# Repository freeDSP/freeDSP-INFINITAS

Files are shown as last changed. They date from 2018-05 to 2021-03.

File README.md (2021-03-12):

# freeDSP Infinitas

USB Audio Class 2 compliant audio interface with up to 32 input and up to 32 output channels and optional ADAU1452 DSP.

BOARD STATUS: RELEASED!

MAIN COORDINATOR: [dspverden](https://github.com/dspverden)

DOCUMENTATION: [Getting Started](https://docs.google.com/document/d/1jxKOcB1Af_6xawysrgFLgatrspSJ-aYZdDhTxlWoG2I)

IMPORTANT:

Please take care on which branch you're currently working!

Branches:

master - this branch always holds the latest released revision

develop - this is the develop branch with new features

## License
This work is licensed under <br />Dieses Werk ist lizenziert unter einer <a rel="license" href="http://creativecommons.org/licenses/by-nc-sa/4.0/">Creative Commons Namensnennung - Nicht-kommerziell - Weitergabe unter gleichen Bedingungen 4.0 International Lizenz</a>.

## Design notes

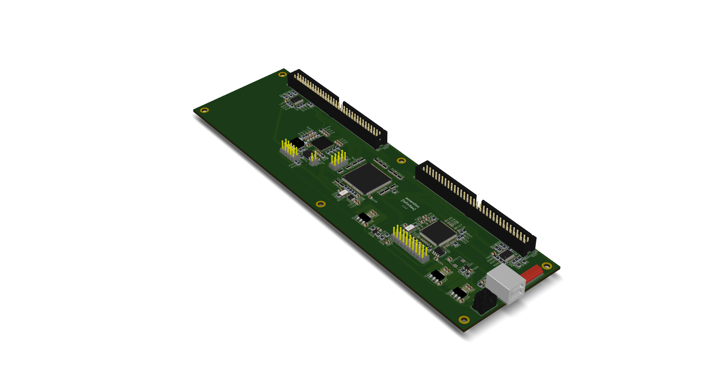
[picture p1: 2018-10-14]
SOURCES/KICAD/infinitas.png

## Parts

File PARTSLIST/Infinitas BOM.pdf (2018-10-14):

### [Infinitas] Core rev 1.0.0 BOM

Reference | Qty | Value1 | Value2 | Footprint | Order No. digikey
B101 B102 B103 B104 B105 B106 | 6 | - | - | MountingHole_3.2mm_M3_DIN965_Pad | -
C102 C122 C125 C127 C128 C130 C131 C133 C205 C206 | 10 | 10u0 | 20% 25V X5R | C0805-X7R | 490-10748-1-ND
C101 C103 C104 C105 C106 C107 C108 C109 C110 C111 C112 C113 C114 C115 C116 C117 C118 C119 C120 C121 C124 C126 C129 C132 C202 C203 C204 C207 | 28 | 100n | 5% 50V X7R | C0805-X7R | 399-1170-1-ND
C123 | 1 | 22u0 | 20% 10V X5R | C0805-X7R | 490-10511-1-ND
C201 | 1 | 10n0 | 10% 50V X7R | C0805-X7R | 311-1136-1-ND
C208 | 1 | 1n00 | 10% 50V X7R | C0805-X7R | 399-1147-1-ND
C209 C210 C211 C212 C213 C214 C215 C216 C217 C218 C219 C220 C221 C222 C223 C224 C225 C226 C227 C228 C229 C230 C231 C232 C233 | 25 | 100n | 10% 10V X7R | C_0402 | 490-6321-1-ND
D201 | 1 | MBR120VLSFT | Schottky 20V 1 A | SOD123 | MBR120VLSFT3GOSCT-ND
IC101 | 1 | CS2100CP | Fractional-N Clock Multiplier | MSOP-10_3x3mm_Pitch0.5mm | 598-1750-ND
IC102 IC103 | 2 | PCA9545APW | I2C Switch 4ch | TSSOP-20_4.4x6.5mm_Pitch0.65mm | 568-1865-1-ND
IC104 | 1 | LCMXO2-1200HC-6TG144C | FPGA | TQFP-144_20x20mm_Pitch0.5mm | 220-2040-ND
IC105 | 1 | TLV62565 | 1.5A | SOT-23-5 | 296-43657-1-ND
IC106 | 1 | ADM811TARTZ | Spannungsmonitor | SOT-143 | ADM811TARTZ-REELCT-ND
IC107 | 1 | LM1117MP-5.0 | LDO | SOT223 | LM1117MP-5.0/NOPBCT-ND
IC108 IC109 | 2 | NCP1117LPST33 | LDO | SOT223 | NCP1117LPST33T3GOSCT-ND
IC201 | 1 | XE216-512-TQ128 | xCore | TQFP-128_14x14mm_Pitch0.4mm_EP_Handsoldering | 880-1096-ND
IC202 | 1 | NCP4681DSQ25T1G | 2,5V 150mA | SC-70-5 | NCP4681DSQ25T1GOSCT-ND
IC203 | 1 | IS25LP080D | 8Mb | SOIC8_3.9x4.9mm_Pitch1.27mm | 706-1580-ND
IC204 | 1 | NC7WZ07 | Noninverting Buffer | SC-70-6 | NC7WZ07P6XCT-ND
L101 | 1 | 2u20 | 30% 4.5A 26 mOhm | MCSDRH73B | 811-1157-1-ND
OSC101 | 1 | 24M576 | - | ASFL1 | 300-8253-1-ND
OSC201 | 1 | 24M0 | - | ASFL1 | 300-8252-1-ND
R101 R201 R213 R214 | 4 | 10K0 | 1% 0.125W Thick | C0805-RES | 311-10.0KCRCT-ND
R118 | 1 | 4K70 | 1% 0.125W Thick | C0805-RES | 311-4.70KCRCT-ND
R102 R103 R104 R105 R112 R113 R114 R115 R124 R125 R126 R127 R134 R135 R136 R137 R211 R212 | 18 | 2K00 | 1% 0.125W Thick | C0805-RES | 311-2.00KCRCT-ND
R106 R107 R108 R109 R110 R111 R128 R129 R130 R131 R132 R133 | 12 | 47K0 | 1% 0.125W Thick | C0805-RES | 311-47.0KCRCT-ND

1

freeDSP Option
C301 C304 C308 C313 | 4 | 10u0 | 20% 25V X5R | C0805-X7R | 490-10748-1-ND
C302 C305 C307 C309 C310 C311 C312 C314 C315 C316 C317 | 11 | 100n | 5% 50V X7R | C0805-X7R | 399-1170-1-ND
C303 | 1 | 5n60 | 10% 50V X7R | C0805-X7R | 311-1134-1-ND
C306 | 1 | 150p | 5% 50V C0G | C0805-X7R | 399-1125-1-ND
FER301 FER302 | 2 | 600R | @100MHz 600mA | C0805-RES | 490-1040-1-ND
IC301 | 1 | ADAU1452 | - | QFP72_10x10_EP_Handsoldering | ADAU1452WBCPZ-ND
IC302 | 1 | 25AA1024 | 1Mbit | SOIJ-8_5.3x5.3mm_Pitch1.27mm | 25AA1024T-I/SMCT-ND
JP301 | 1 | Jumper | - | HDR_01x02 | 732-5315-ND
Q301 | 1 | STD2805 | PNP 60V 5A 150MHz 15W | TO-252-2Lead | 497-7465-1-ND
R308 R313 R314 | 3 | 10K0 | 1% 0.125W Thick | C0805-RES | 311-10.0KCRCT-ND
R302 R303 R304 R305 R306 | 5 | 51R0 | 1% 0.125W Thick | C0805-RES | 311-51.0CRCT-ND
R301 | 1 | 1K00 | 1% 0.125W Thick | C0805-RES | 311-1.00KCRCT-ND
R307 | 1 | 4K32 | 1% 0.125W Thick | C0805-RES | 311-4.32KCRCT-ND
R309 R310 R315 R316 | 4 | DNP | - | C0805-RES | -
R311 R312 R317 R318 | 4 | 0R00 | 1% 0.125W Thick | C0805-RES | 311-0.0ARCT-ND
X301 | 1 | HDR-02x05 | - | HDR_02x05 | 952-2117-ND
Reference | Qty | Value1 | Value2 | Footprint | Order No. digikey
R119 R120 R121 R123 R138 R139 R140 R141 R143 R145 R147 R148 R150 R151 R152 R204 | 16 | 51R0 | 5% 62,5mW | R_Array_Convex_4x0603 | TC164J-51CT-ND
R116 R117 R122 R142 R144 R146 R149 R202 R205 R206 R209 R210 | 12 | 51R0 | 1% 0.125W Thick | C0805-RES | 311-51.0CRCT-ND
R153 R207 | 2 | 1K00 | 1% 0.125W Thick | C0805-RES | 311-1.00KCRCT-ND
R154 | 1 | 80K6 | 1% 0.125W Thick | C0805-RES | 311-80.6KCRCT-ND
R155 R215 | 2 | 100K | 1% 0.125W Thick | C0805-RES | 311-100KCRCT-ND
R156 | 1 | 120K | 1% 0.125W Thick | C0805-RES | 311-120KCRCT-ND
R203 | 1 | 4R70 | 1% 0.125W Thick | C0805-RES | 311-4.70CRCT-ND
R208 | 1 | 43R2 | 1% 0.125W Thick | C0805-RES | P43.2CCT-ND
X101 | 1 | HDR-02x04 | - | HDR_02x04 | 952-3276-ND
X102 X103 | 2 | IDC64 | - | IDC64 | ED10532-ND
X104 | 1 | MicroMatch-10 | - | MM-10G | A110869-ND
X105 | 1 | MicroFit3 02x02 | - | Microfit3_43045-0428 | WM10670-ND
X201 | 1 | HDR-02x10 | - | HDR_02x10 | S2011EC-10-ND
X202 | 1 | USB_B | horizontal | USB_B | ED2983-ND
X203 | 1 | HDR-01x04 | - | HDR_01x04 | 732-5317-ND

2

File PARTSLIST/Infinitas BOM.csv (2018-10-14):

Reference | Quantity | Value | Footprint | Datasheet | Value1 | Value2 | digikey
B101 B102 B103 B104 B105 B106 | 6 | TEST_1P | rklib:MountingHole_3.2mm_M3_DIN965_Pad |  | - | - | -
C102 C122 C125 C127 C128 C130 C131 C133 C205 C206 C301 C304 C308 C313 | 14 | CAP_10u0_25V_X5R_0805 | rklib:C0805-X7R |  | 10u0 | 20% 25V X5R | 490-10748-1-ND
C101 C103 C104 C105 C106 C107 C108 C109 C110 C111 C112 C113 C114 C115 C116 C117 C118 C119 C120 C121 C124 C126 C129 C132 C202 C203 C204 C207 C302 C305 C307 C309 C310 C311 C312 C314 C315 C316 C317 | 39 | CAP_100n_50V_X7R_0805 | rklib:C0805-X7R |  | 100n | 5% 50V X7R | 399-1170-1-ND
C123 | 1 | CAP_22u0_10V_X5R_0805 | rklib:C0805-X7R |  | 22u0 | 20% 10V X5R | 490-10511-1-ND
C201 | 1 | CAP_10n0_50V_X7R_0805 | rklib:C0805-X7R |  | 10n0 | 10% 50V X7R | 311-1136-1-ND
C208 | 1 | CAP_1n00_50V_X7R_0805 | rklib:C0805-X7R |  | 1n00 | 10% 50V X7R | 399-1147-1-ND
C209 C210 C211 C212 C213 C214 C215 C216 C217 C218 C219 C220 C221 C222 C223 C224 C225 C226 C227 C228 C229 C230 C231 C232 C233 | 25 | CAP_100n_10V_X7R_0402 | Capacitors_SMD:C_0402 |  | 100n | 10% 10V X7R | 490-6321-1-ND
C303 | 1 | CAP_5n60_50V_X7R_0805 | rklib:C0805-X7R |  | 5n60 | 10% 50V X7R | 311-1134-1-ND
C306 | 1 | CAP_150p_50V_C0G_0805 | rklib:C0805-X7R |  | 150p | 5% 50V C0G | 399-1125-1-ND
D201 | 1 | DIO_MBR120VLSFT | rklib:SOD123 |  | MBR120VLSFT | Schottky 20V 1 A | MBR120VLSFT3GOSCT-ND
FER301 FER302 | 2 | FER_600R_600MA_0805 | rklib:C0805-RES |  | 600R | @100MHz 600mA | 490-1040-1-ND
IC101 | 1 | IC_CS2100CP | Housings_SSOP:MSOP-10_3x3mm_Pitch0.5mm |  | CS2100CP | Fractional-N Clock Multiplier | 598-1750-ND
IC102 IC103 | 2 | IC_PCA9545APW | Housings_SSOP:TSSOP-20_4.4x6.5mm_Pitch0.65mm |  | PCA9545APW | I2C Switch 4ch | 568-1865-1-ND
IC104 | 1 | IC_LCMXO2-1200HC-6TG144C | Housings_QFP:TQFP-144_20x20mm_Pitch0.5mm |  | LCMXO2-1200HC-6TG144C | FPGA | 220-2040-ND
IC105 | 1 | IC_TLV62565 | TO_SOT_Packages_SMD:SOT-23-5 |  | TLV62565 | 1.5A | 296-43657-1-ND
IC106 | 1 | IC_ADM811TARTZ | TO_SOT_Packages_SMD:SOT-143 |  | ADM811TARTZ | Spannungsmonitor | ADM811TARTZ-REELCT-ND
IC107 | 1 | IC_LM1117MP-5.0 | rklib:SOT223 |  | LM1117MP-5.0 | LDO | LM1117MP-5.0/NOPBCT-ND
IC108 IC109 | 2 | IC_NCP1117LPST33 | rklib:SOT223 |  | NCP1117LPST33 | LDO | NCP1117LPST33T3GOSCT-ND
IC201 | 1 | IC_XE216-512-TQ128 | rklib:TQFP-128_14x14mm_Pitch0.4mm_EP_Handsoldering |  | XE216-512-TQ128 | xCore | 880-1096-ND
IC202 | 1 | IC_NCP4681DSQ25T1G | TO_SOT_Packages_SMD:SC-70-5 |  | NCP4681DSQ25T1G | 2,5V 150mA | NCP4681DSQ25T1GOSCT-ND
IC203 | 1 | IC_IS25LP080D | rklib:SOIC8_3.9x4.9mm_Pitch1.27mm |  | IS25LP080D | 8Mb | 706-1580-ND
IC204 | 1 | IC_NC7WZ07 | TO_SOT_Packages_SMD:SC-70-6 |  | NC7WZ07 | Noninverting Buffer | NC7WZ07P6XCT-ND
IC301 | 1 | IC_ADAU1452 | rklib:QFP72_10x10_EP_Handsoldering |  | ADAU1452 | - | ADAU1452WBCPZ-ND
IC302 | 1 | IC_25AA1024 | Housings_SOIC:SOIJ-8_5.3x5.3mm_Pitch1.27mm |  | 25AA1024 | 1Mbit | 25AA1024T-I/SMCT-ND
JP301 | 1 | CON_JUMPER | rklib:HDR_01x02 |  | Jumper | - | 732-5315-ND
L101 | 1 | IND_2U20_30%_4A5 | rklib:MCSDRH73B |  | 2u20 | 30% 4.5A 26 mOhm | 811-1157-1-ND
OSC101 | 1 | OSC_24M576 | rklib:ASFL1 |  | 24M576 | - | 300-8253-1-ND
OSC201 | 1 | OSC_24M0 | rklib:ASFL1 |  | 24M0 | - | 300-8252-1-ND
Q301 | 1 | Q_STD2805 | TO_SOT_Packages_SMD:TO-252-2Lead |  | STD2805 | PNP 60V 5A 150MHz 15W | 497-7465-1-ND
R101 R201 R213 R214 R308 R313 R314 | 7 | RES_10K0_1%_0.125W_Thick_0805 | rklib:C0805-RES |  | 10K0 | 1% 0.125W Thick | 311-10.0KCRCT-ND
R118 | 1 | RES_4K70_1%_0.125W_Thick_0805 | rklib:C0805-RES |  | 4K70 | 1% 0.125W Thick | 311-4.70KCRCT-ND
R102 R103 R104 R105 R112 R113 R114 R115 R124 R125 R126 R127 R134 R135 R136 R137 R211 R212 | 18 | RES_2K00_1%_0.125W_Thick_0805 | rklib:C0805-RES |  | 2K00 | 1% 0.125W Thick | 311-2.00KCRCT-ND
R106 R107 R108 R109 R110 R111 R128 R129 R130 R131 R132 R133 | 12 | RES_47K0_1%_0.125W_Thick_0805 | rklib:C0805-RES |  | 47K0 | 1% 0.125W Thick | 311-47.0KCRCT-ND
R119 R120 R121 R123 R138 R139 R140 R141 R143 R145 R147 R148 R150 R151 R152 R204 | 16 | RES_51R0_5%_4x0603 | Resistors_SMD:R_Array_Convex_4x0603 |  | 51R0 | 5% 62,5mW | TC164J-51CT-ND
R116 R117 R122 R142 R144 R146 R149 R202 R205 R206 R209 R210 R302 R303 R304 R305 R306 | 17 | RES_51R0_1%_0.125W_Thick_0805 | rklib:C0805-RES |  | 51R0 | 1% 0.125W Thick | 311-51.0CRCT-ND
R153 R207 R301 | 3 | RES_1K00_1%_0.125W_Thick_0805 | rklib:C0805-RES |  | 1K00 | 1% 0.125W Thick | 311-1.00KCRCT-ND
R154 | 1 | RES_80K6_1%_0.125W_Thick_0805 | rklib:C0805-RES |  | 80K6 | 1% 0.125W Thick | 311-80.6KCRCT-ND
R155 R215 | 2 | RES_100K_1%_0.125W_Thick_0805 | rklib:C0805-RES |  | 100K | 1% 0.125W Thick | 311-100KCRCT-ND
R156 | 1 | RES_120K_1%_0.125W_Thick_0805 | rklib:C0805-RES |  | 120K | 1% 0.125W Thick | 311-120KCRCT-ND
R203 | 1 | RES_4R70_1%_0.125W_Thick_0805 | rklib:C0805-RES |  | 4R70 | 1% 0.125W Thick | 311-4.70CRCT-ND
R208 | 1 | RES_43R2_1%_0.125W_Thick_0805 | rklib:C0805-RES |  | 43R2 | 1% 0.125W Thick | P43.2CCT-ND
R307 | 1 | RES_4K32_1%_0.125W_Thick_0805 | rklib:C0805-RES |  | 4K32 | 1% 0.125W Thick | 311-4.32KCRCT-ND
R309 R310 R315 R316 | 4 | DNP | rklib:C0805-RES |  | DNP | - | -
R311 R312 R317 R318 | 4 | RES_0R00_1%_0.125W_Thick_0805 | rklib:C0805-RES |  | 0R00 | 1% 0.125W Thick | 311-0.0ARCT-ND
X101 | 1 | CON_HDR_02x04 | rklib:HDR_02x04 |  | HDR-02x04 | - | 952-3276-ND
X102 X103 | 2 | CON_IDC64 | rklib:IDC64 |  | IDC64 | - | ED10532-ND
X104 | 1 | CON_MicroMatch-10G | rklib:MM-10G |  | MicroMatch-10 | - | A110869-ND
X105 | 1 | CON_MicroFit3_02x02 | rklib:Microfit3_43045-0428 |  | MicroFit3 02x02 | - | WM10670-ND
X201 | 1 | CON_HDR_02x10 | rklib:HDR_02x10 |  | HDR-02x10 | - | S2011EC-10-ND
X202 | 1 | CON_USB_B | rklib:USB_B |  | USB_B | horizontal | ED2983-ND
X203 | 1 | CON_HDR_01x04 | rklib:HDR_01x04 |  | HDR-01x04 | - | 732-5317-ND
X301 | 1 | CON_HDR_02x05 | rklib:HDR_02x05 |  | HDR-02x05 | - | 952-2117-ND

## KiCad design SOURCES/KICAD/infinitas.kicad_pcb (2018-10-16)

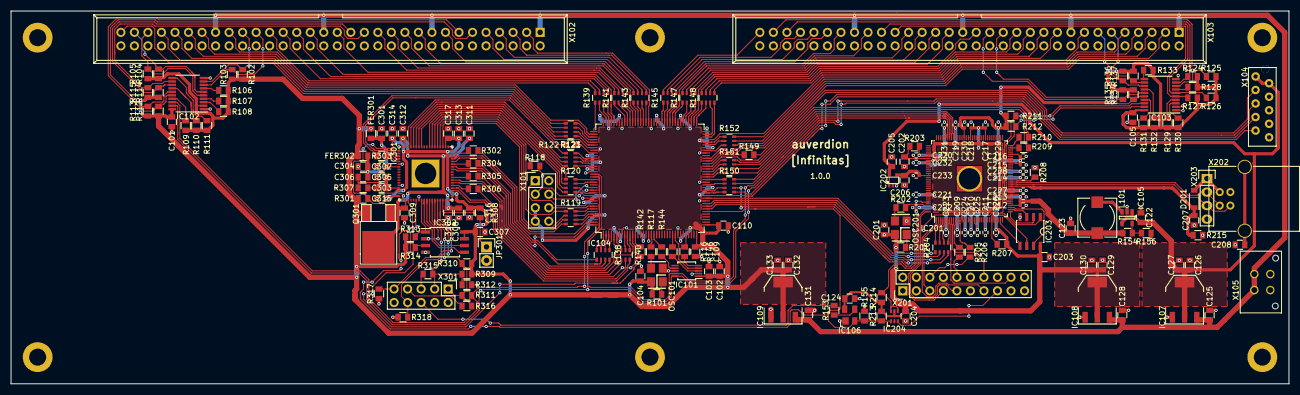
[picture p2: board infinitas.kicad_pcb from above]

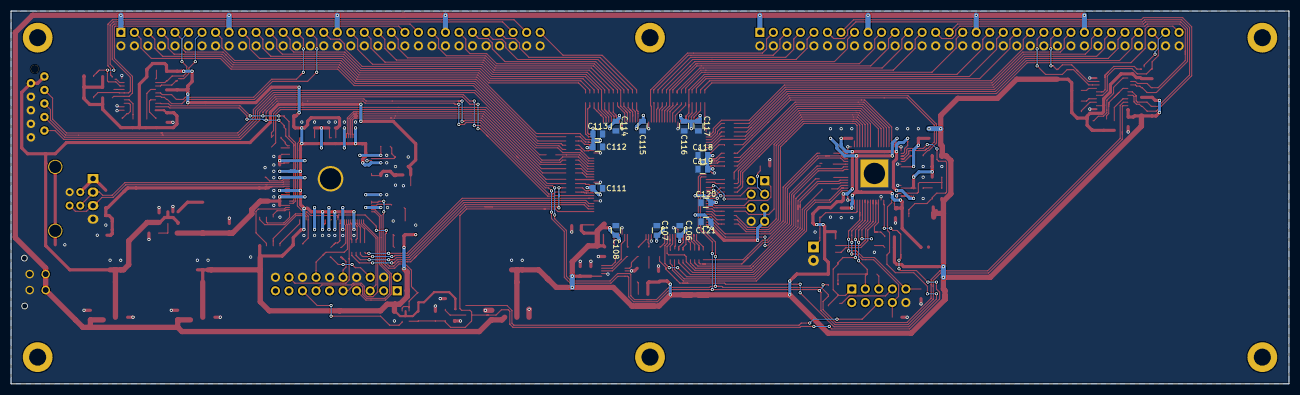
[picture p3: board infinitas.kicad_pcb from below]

Board: 2 copper layers, 240.0 x 70.0 mm, 210 parts (14 on the bottom side), 258 nets.

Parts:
B101, B102, B103, B104, B105, B106: TEST_1P; MountingHole_3.2mm_M3_DIN965_Pad
C101, C103, C104, C105, C106, C107, C108, C109, C110, C111, C112, C113, C114, C115, C116, C117, C118, C119, C120, C121, C124, C126, C129, C132, C202, C203, C204, C207, C302, C305, C307, C309, C310, C311, C312, C314, C315, C316, C317: CAP_100n_50V_X7R_0805; C0805-X7R
C102, C122, C125, C127, C128, C130, C131, C133, C205, C206, C301, C304, C308, C313: CAP_10u0_25V_X5R_0805; C0805-X7R
C123: CAP_22u0_10V_X5R_0805; C0805-X7R
C201: CAP_10n0_50V_X7R_0805; C0805-X7R
C208: CAP_1n00_50V_X7R_0805; C0805-X7R
C209, C210, C211, C212, C213, C214, C215, C216, C217, C218, C219, C220, C221, C222, C223, C224, C225, C226, C227, C228, C229, C230, C231, C232, C233: CAP_100n_10V_X7R_0402; C0402-X7R
C303: CAP_5n60_50V_X7R_0805; C0805-X7R
C306: CAP_150p_50V_C0G_0805; C0805-X7R
D201: DIO_MBR120VLSFT; SOD123
FER301, FER302: FER_600R_600MA_0805; C0805-RES
IC101: IC_CS2100CP; MSOP10_3x3mm_Pitch0.5mm
IC102, IC103: IC_PCA9545APW; TSSOP20_4.4x6.5mm_Pitch0.65mm
IC104: IC_LCMXO2-1200HC-6TG144C; TQFP144_20x20mm_Pitch0.5mm
IC105: IC_TLV62565; SOT23-5
IC106: IC_ADM811TARTZ; SOT143
IC107: IC_LM1117MP-5.0; SOT223
IC108, IC109: IC_NCP1117LPST33; SOT223
IC201: IC_XE216-512-TQ128; TQFP-128_14x14mm_Pitch0.4mm_EP_Handsoldering
IC202: IC_NCP4681DSQ25T1G; SC70-5
IC203: IC_IS25LP080D; SOIC8_3.9x4.9mm_Pitch1.27mm
IC204: IC_NC7WZ07; SC70-6
IC301: IC_ADAU1452; LFCSP72_10x10_EP_Handsoldering
IC302: IC_25AA1024; SOIJ8_5.3x5.3mm_P1.27mm
JP301: CON_JUMPER; HDR_01x02
L101: IND_2U20_30%_4A5; MCSDRH73B
OSC101: OSC_24M576; ASFL1
OSC201: OSC_24M0; ASFL1
Q301: Q_STD2805; TO252-2Lead
R101, R201, R213, R214, R308, R313, R314: RES_10K0_1%_0.125W_Thick_0805; C0805-RES
R102, R103, R104, R105, R112, R113, R114, R115, R124, R125, R126, R127, R134, R135, R136, R137, R211, R212: RES_2K00_1%_0.125W_Thick_0805; C0805-RES
R106, R107, R108, R109, R110, R111, R128, R129, R130, R131, R132, R133: RES_47K0_1%_0.125W_Thick_0805; C0805-RES
R116, R117, R122, R142, R144, R146, R149, R202, R205, R206, R209, R210, R302, R303, R304, R305, R306: RES_51R0_1%_0.125W_Thick_0805; C0805-RES
R118: RES_4K70_1%_0.125W_Thick_0805; C0805-RES
R119, R120, R121, R123, R138, R139, R140, R141, R143, R145, R147, R148, R150, R151, R152, R204: RES_51R0_5%_4x0603; RArray_Convex_4x0603
R153, R207, R301: RES_1K00_1%_0.125W_Thick_0805; C0805-RES
R154: RES_80K6_1%_0.125W_Thick_0805; C0805-RES
R155, R215: RES_100K_1%_0.125W_Thick_0805; C0805-RES
R156: RES_120K_1%_0.125W_Thick_0805; C0805-RES
R203: RES_4R70_1%_0.125W_Thick_0805; C0805-RES
R208: RES_43R2_1%_0.125W_Thick_0805; C0805-RES
R307: RES_4K32_1%_0.125W_Thick_0805; C0805-RES
R309, R310, R315, R316: DNP; C0805-RES
R311, R312, R317, R318: RES_0R00_1%_0.125W_Thick_0805; C0805-RES
X101: CON_HDR_02x04; HDR_02x04
X102, X103: CON_IDC64; IDC64
X104: CON_MicroMatch-10G; MM-10G
X105: CON_MicroFit3_02x02; Microfit3_43045-0428
X201: CON_HDR_02x10; HDR_02x10
X202: CON_USB_B; USB_B
X203: CON_HDR_01x04; Pin_Header_Straight_1x04
X301: CON_HDR_02x05; HDR_02x05

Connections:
+1V0: C123.1, C209.1, C210.1, C211.1, C212.1, C213.1, C214.1, C215.1, C216.1, C217.1, C218.1, C219.1, C220.1, C221.1, C222.1, IC201.11, IC201.16, IC201.17, IC201.24, IC201.36, IC201.41, IC201.49, IC201.56, IC201.60, IC201.73, IC201.80, IC201.81, IC201.87, IC201.101, IC201.102, IC201.120, IC201.126, L101.2, R154.1, R203.2
+2V5: C206.2, C233.1, IC201.110, IC201.111, IC202.4
+3V3: C101.2, C102.2, C103.2, C104.2, C106.2, C107.2, C108.2, C109.2, C110.2, C111.2, C112.2, C113.2, C114.2, C115.2, C116.2, C117.2, C118.2, C119.2, C120.2, C121.2, C132.2, C133.2, C307.2, C313.2, C314.2, C315.2, C316.2, C317.2, FER301.1, FER302.1, IC101.1, IC102.2, IC102.20, IC104.7, IC104.16, IC104.30, IC104.36, IC104.37, IC104.51, IC104.66, IC104.72, IC104.79, IC104.88, IC104.102, IC104.108, IC104.118, IC104.123, IC104.135, IC104.144, IC109.2, IC109.4, IC301.2, IC301.18, IC301.38, IC301.56, IC302.7, IC302.8, OSC101.4, Q301.3, R101.2, R102.2, R103.2, R104.2, R105.2, R106.2, R107.2, R108.2, R109.2, R110.2, R111.2, R112.2, R113.2, R114.2, R115.2, R301.1, R308.2, R309.1, R310.1, R313.1, R314.1, X101.5, X101.7
+5V: C122.2, C126.2, C127.2, C205.2, IC105.1, IC105.4, IC107.2, IC107.4, IC202.1, IC202.5, X104.1, X104.2
+12V: C125.2, C128.2, C131.2, IC107.3, IC108.3, IC109.3, X102.1, X102.17, X102.33, X102.49, X103.1, X103.17, X103.33, X103.49, X105.1, X105.2
/BCLK:1: R143.6, X102.7
/BCLK:2: R152.6, X103.7
/BCLK:3: R141.6, X102.23
/BCLK:4: R148.6, X103.23
/BCLK:5: R139.6, X102.39
/BCLK:6: R147.6, X103.39
/BCLK:7: R123.6, X102.55
/BCLK:8: R145.6, X103.55
/BCLKIN0: IC301.57, R119.4
/BCLKIN1: IC301.60, R119.1
/BCLKIN2: IC301.65, R120.2
/BCLKIN3: IC301.68, R121.3
/BCLKOUT0: IC301.40, R140.7
/BCLKOUT1: IC301.43, R140.5
/BCLKOUT2: IC301.48, R138.7
/BCLKOUT3: IC301.51, R138.5
/CLKREF: IC101.7, R144.1
/DSP/MISO: R315.1, X301.5
/DSP/MOSI: IC301.32, R318.2, X301.8
/DSP/SCLK: R316.1, X301.7
/DSP/~SS: IC301.33, R317.2, X301.9
/LRCK:1: R143.7, X102.9
/LRCK:2: R152.7, X103.9
/LRCK:3: R141.7, X102.25
/LRCK:4: R148.7, X103.25
/LRCK:5: R139.7, X102.41
/LRCK:6: R147.7, X103.41
/LRCK:7: R123.7, X102.57
/LRCK:8: R145.7, X103.57
/LRCKIN0: IC301.58, R119.3
/LRCKIN1: IC301.61, R120.4
/LRCKIN2: IC301.66, R120.1
/LRCKIN3: IC301.69, R121.2
/LRCKOUT0: IC301.39, R140.8
/LRCKOUT1: IC301.42, R140.6
/LRCKOUT2: IC301.47, R138.8
/LRCKOUT3: IC301.50, R138.6
/MCLK: IC301.21, R142.1
/MCLK:1: R143.8, X102.15
/MCLK:2: R152.8, X103.15
/MCLK:3: R141.8, X102.31
/MCLK:4: R148.8, X103.31
/MCLK:5: R139.8, X102.47
/MCLK:6: R147.8, X103.47
/MCLK:7: R123.8, X102.63
/MCLK:8: R145.8, X103.63
/MDI:1: IC104.91, X102.3
/MDI:2: IC104.61, X103.3
/MDI:3: IC104.96, X102.19
/MDI:4: IC104.69, X103.19
/MDI:5: IC104.104, X102.35
/MDI:6: IC104.75, X103.35
/MDI:7: IC104.110, X102.51
/MDI:8: IC104.82, X103.51
/MDO:1: R143.5, X102.5
/MDO:2: R152.5, X103.5
/MDO:3: R141.5, X102.21
/MDO:4: R148.5, X103.21
/MDO:5: R139.5, X102.37
/MDO:6: R147.5, X103.37
/MDO:7: R123.5, X102.53
/MDO:8: R145.5, X103.53
/OSC: IC104.19, R117.2
/PLLCLK: IC104.27, R116.1
/PLLLOCKED: IC101.4, IC104.28
/SCL: IC101.9, IC102.18, IC103.18, IC104.126, IC201.37, R211.1, R311.1
/SCL:1: IC102.16, R112.1, X102.13
/SCL:2: IC103.13, R136.1, X103.13
/SCL:3: IC102.13, R114.1, X102.29
/SCL:4: IC103.16, R134.1, X103.29
/SCL:5: IC102.9, R102.1, X102.45
/SCL:6: IC103.6, R126.1, X103.45
/SCL:7: IC102.6, R104.1, X102.61
/SCL:8: IC103.9, R124.1, X103.61
/SDA: IC101.10, IC102.19, IC103.19, IC104.125, IC201.38, R212.1, R312.1
/SDA:1: IC102.15, R113.1, X102.11
/SDA:2: IC103.12, R137.1, X103.11
/SDA:3: IC102.12, R115.1, X102.27
/SDA:4: IC103.15, R135.1, X103.27
/SDA:5: IC102.8, R103.1, X102.43
/SDA:6: IC103.5, R127.1, X103.43
/SDA:7: IC102.5, R105.1, X102.59
/SDA:8: IC103.8, R125.1, X103.59
/SPDIFIN: IC104.48, X104.9
/SPDIFOUT: R150.5, X104.7
/TCK: IC104.131, R118.2, X101.3
/TDI: IC104.136, X101.1
/TDMIN0: IC301.59, R119.2
/TDMIN1: IC301.62, R120.3
/TDMIN2: IC301.67, R121.4
/TDMIN3: IC301.70, R121.1
/TDMOUT0: IC104.12, R306.1
/TDMOUT1: IC104.11, R305.1
/TDMOUT2: IC104.143, R304.1
/TDMOUT3: IC104.142, R302.1
/TDO: IC104.137, X101.6
/TMS: IC104.130, X101.4
/UAC2 Interface/24M: IC201.125, R202.1
/UAC2 Interface/QSPI_D0: IC201.31, IC203.5
/UAC2 Interface/QSPI_D1: IC201.33, IC203.2
/UAC2 Interface/QSPI_D2: IC201.34, IC203.3
/UAC2 Interface/QSPI_D3: IC201.35, IC203.7
/UAC2 Interface/RST_N: IC201.123, IC201.124, IC204.4, IC204.6, R214.1
/UAC2 Interface/SPI_CLK: IC201.28, IC203.6
/UAC2 Interface/SPI_CS: IC201.27, IC203.1, R207.2
/UAC2 Interface/TCK: IC201.128, X201.9
/UAC2 Interface/TDI: IC201.2, X201.5
/UAC2 Interface/TDO: IC201.1, X201.13
/UAC2 Interface/TMS: IC201.127, X201.7
/UAC2 Interface/USBD_N: IC201.47, X202.2, X203.2
/UAC2 Interface/USBD_P: IC201.46, X202.3, X203.3
/UAC2 Interface/VBUS: C207.2, D201.1, IC201.45, R215.2
/UAC2 Interface/XL_DN0: IC201.9, X201.14
/UAC2 Interface/XL_DN1: IC201.8, X201.18
/UAC2 Interface/XL_UP0: R205.2, X201.10
/UAC2 Interface/XL_UP1: R206.2, X201.6
/UAC2 Interface/XSYS_RST_N: IC204.3, X201.15
/WCLKIN: IC104.59, X104.5
/WCLKOUT: R149.1, X104.3
/WCLKREF: IC101.5, R146.1
/XBCLK: R151.7, R209.2
/XLRCK: R151.8, R210.2
/XMCLK: IC201.13, IC201.66, R150.6
/XTDMIN1: IC201.88, R151.6
/XTDMIN2: IC201.89, R151.5
/XTDMIN3: IC201.90, R150.8
/XTDMIN4: IC201.91, R150.7
/XTDMOUT1: IC104.43, R204.4
/XTDMOUT2: IC104.44, R204.3
/XTDMOUT3: IC104.45, R204.2
/XTDMOUT4: IC104.47, R204.1
/dspSPDIFIN: IC301.4, R122.1
/dspSPDIFOUT: IC104.115, R303.2
/~RST: IC104.42, IC106.2, IC204.1, IC301.24, R155.2, R213.1
/~USBRST: R153.1, X301.6
GND: C101.1, C102.1, C103.1, C104.1, C105.1, C106.1, C107.1, C108.1, C109.1, C110.1, C111.1, C112.1, C113.1, C114.1, C115.1, C116.1, C117.1, C118.1, C119.1, C120.1, C121.1, C122.1, C123.2, C124.1, C125.1, C126.1, C127.1, C128.1, C129.1, C130.1, C131.1, C132.1, C133.1, C201.1, C202.2, C203.1, C204.1, C205.1, C206.1, C207.1, C208.1, C209.2, C210.2, C211.2, C212.2, C213.2, C214.2, C215.2, C216.2, C217.2, C218.2, C219.2, C220.2, C221.2, C222.2, C223.2, C224.2, C225.2, C226.2, C227.2, C228.2, C229.2, C230.2, C231.2, C232.2, C233.2, C301.1, C302.1, C304.1, C305.1, C307.1, C308.1, C309.1, C310.1, C311.1, C312.1, C313.1, C314.1, C315.1, C316.1, C317.1, IC101.2, IC101.8, IC102.1, IC102.10, IC103.1, IC103.2, IC103.10, IC104.8, IC104.18, IC104.29, IC104.46, IC104.53, IC104.64, IC104.80, IC104.90, IC104.101, IC104.116, IC104.124, IC104.134, IC105.2, IC106.1, IC107.1, IC108.1, IC109.1, IC201.104, IC201.129, IC202.3, IC203.4, IC301.1, IC301.6, IC301.14, IC301.17, IC301.19, IC301.25, IC301.36, IC301.37, IC301.54, IC301.55, IC301.72, IC301.73, IC302.4, JP301.2, OSC101.2, OSC201.2, R118.1, R155.1, R156.1, R208.1, R215.1, R317.1, R318.1, X101.8, X102.2, X102.4, X102.6, X102.8, X102.10, X102.12, X102.14, X102.16, X102.18, X102.20, X102.22, X102.24, X102.26, X102.28, X102.30, X102.32, X102.34, X102.36, X102.38, X102.40, X102.42, X102.44, X102.46, X102.48, X102.50, X102.52, X102.54, X102.56, X102.58, X102.60, X102.62, X102.64, X103.2, X103.4, X103.6, X103.8, X103.10, X103.12, X103.14, X103.16, X103.18, X103.20, X103.22, X103.24, X103.26, X103.28, X103.30, X103.32, X103.34, X103.36, X103.38, X103.40, X103.42, X103.44, X103.46, X103.48, X103.50, X103.52, X103.54, X103.56, X103.58, X103.60, X103.62, X103.64, X104.4, X104.6, X104.8, X104.10, X105.3, X105.4, X201.4, X201.8, X201.12, X201.16, X201.20, X202.4, X203.4, X301.10
unnamed: C202.1, IC201.103, R203.1
unnamed: C208.2, X202.5
unnamed: C301.2, C302.2, FER301.2, IC301.7
unnamed: C303.1, C304.2, C305.2, C306.1, FER302.2, IC301.15
unnamed: C303.2, R307.1
unnamed: C306.2, IC301.16, R307.2
unnamed: D201.2, X202.1, X203.1
unnamed: IC101.3, R116.2
unnamed: IC102.3, R108.1
unnamed: IC102.4, R107.1
unnamed: IC102.7, R106.1
unnamed: IC102.11, R111.1
unnamed: IC102.14, R110.1
unnamed: IC102.17, R109.1
unnamed: IC103.3, R130.1
unnamed: IC103.4, R129.1
unnamed: IC103.7, R128.1
unnamed: IC103.11, R133.1
unnamed: IC103.14, R132.1
unnamed: IC103.17, R131.1
unnamed: IC104.1, R138.4
unnamed: IC104.2, R138.3
unnamed: IC104.3, R138.2
unnamed: IC104.4, R138.1
unnamed: IC104.5, R140.4
unnamed: IC104.6, R140.3
unnamed: IC104.9, R140.2
unnamed: IC104.10, R140.1
unnamed: IC104.13, R142.2
unnamed: IC104.20, R144.2
unnamed: IC104.32, R146.2
unnamed: IC104.49, R150.4
unnamed: IC104.50, R150.3
unnamed: IC104.52, R150.2
unnamed: IC104.54, R150.1
unnamed: IC104.55, R151.4
unnamed: IC104.56, R151.3
unnamed: IC104.57, R151.2
unnamed: IC104.58, R151.1
unnamed: IC104.60, R149.2
unnamed: IC104.62, R152.4
unnamed: IC104.65, R152.3
unnamed: IC104.67, R152.2
unnamed: IC104.68, R152.1
unnamed: IC104.70, R148.4
unnamed: IC104.71, R148.3
unnamed: IC104.73, R148.2
unnamed: IC104.74, R148.1
unnamed: IC104.76, R147.4
unnamed: IC104.77, R147.3
unnamed: IC104.78, R147.2
unnamed: IC104.81, R147.1
unnamed: IC104.83, R145.4
unnamed: IC104.84, R145.3
unnamed: IC104.85, R145.2
unnamed: IC104.86, R145.1
unnamed: IC104.92, R143.4
unnamed: IC104.93, R143.3
unnamed: IC104.94, R143.2
unnamed: IC104.95, R143.1
unnamed: IC104.97, R141.4
unnamed: IC104.98, R141.3
unnamed: IC104.99, R141.2
unnamed: IC104.100, R141.1
unnamed: IC104.105, R139.4
unnamed: IC104.106, R139.3
unnamed: IC104.107, R139.2
unnamed: IC104.109, R139.1
unnamed: IC104.111, R123.4
unnamed: IC104.112, R123.3
unnamed: IC104.113, R123.2
unnamed: IC104.114, R123.1
unnamed: IC104.117, R122.2
unnamed: IC104.119, R121.8
unnamed: IC104.120, R121.7
unnamed: IC104.121, R121.6
unnamed: IC104.122, R121.5
unnamed: IC104.127, R120.8
unnamed: IC104.128, R120.7
unnamed: IC104.132, R120.6
unnamed: IC104.133, R120.5
unnamed: IC104.138, R119.8
unnamed: IC104.139, R119.7
unnamed: IC104.140, R119.6
unnamed: IC104.141, R119.5
unnamed: IC105.3, L101.1
unnamed: IC105.5, R154.2, R156.2
unnamed: IC106.3, R153.2
unnamed: IC201.3, R204.8
unnamed: IC201.4, R204.7
unnamed: IC201.5, R204.6
unnamed: IC201.7, R204.5
unnamed: IC201.10, R205.1
unnamed: IC201.12, R206.1
unnamed: IC201.48, R208.2
unnamed: IC201.63, R209.1
unnamed: IC201.64, R210.1
unnamed: IC301.3, Q301.1, R301.2
unnamed: IC301.5, R303.1
unnamed: IC301.26, IC302.1, R313.2
unnamed: IC301.27, IC302.5
unnamed: IC301.28, IC302.6
unnamed: IC301.29, IC302.2
unnamed: IC301.30, R309.2, R312.2, R315.2, X301.3
unnamed: IC301.31, R310.2, R311.2, R316.2, X301.1
unnamed: IC301.34, JP301.1, R308.1
unnamed: IC301.41, R306.2
unnamed: IC301.44, R305.2
unnamed: IC301.49, R304.2
unnamed: IC301.52, R302.2
unnamed: IC302.3, R314.2
unnamed: OSC101.1, R101.1
unnamed: OSC101.3, R117.1
unnamed: OSC201.1, R201.1
unnamed: OSC201.3, R202.2
VDD: C105.2, C124.2, C129.2, C130.2, C201.2, C203.2, C204.2, C223.1, C224.1, C225.1, C226.1, C227.1, C228.1, C229.1, C230.1, C231.1, C232.1, IC103.20, IC106.4, IC108.2, IC108.4, IC201.6, IC201.14, IC201.19, IC201.29, IC201.42, IC201.44, IC201.52, IC201.67, IC201.83, IC201.92, IC201.105, IC203.8, IC204.5, OSC201.4, R124.2, R125.2, R126.2, R127.2, R128.2, R129.2, R130.2, R131.2, R132.2, R133.2, R134.2, R135.2, R136.2, R137.2, R201.2, R207.1, R211.2, R212.2, R213.2, R214.2
VPP: C308.2, C309.2, C310.2, C311.2, C312.2, IC301.20, IC301.35, IC301.53, IC301.71, Q301.2

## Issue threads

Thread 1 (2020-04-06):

Part is obsolete

tschiemer, 2020-04-06:
According to digitec this part is obsolete (can not be ordered) and would need a replacement

ON Semiconductor: NCP4681, NCP4684
150 mA, Ultra Low
Quiescent Current, Low
Dropout Regulator

https://www.digikey.de/products/de?keywords=NCP4681DSQ25T1GOSCT-ND

dsollows, 2020-09-28:
Confirmed the same result here.
Can't seem to find suitable replacement with the same pin out.  PCB design may need modifications to support current production alternates.  Not sure that an adapter board would be feasible without looking into clearances around IC202.

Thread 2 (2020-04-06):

Feature: AVB

tschiemer, 2020-04-06:
Hi there!

Thanks for all the work!

What I think would be a highly appreciated feature would be network/ethernet connectivity - in particular in hindsight with networked audio, ie [AVB](https://en.wikipedia.org/wiki/Audio_Video_Bridging).

This can be as alternative to USB-connectivity or additionally.

From my little browsing of the documentation (seemingly 4 expansion boards can be added to infinitas). What's the channel limit of each expansion board? I mean, if I could attach a 32 channel AVB expansion board and that 32 channel ADAT expansion board in the making to create a AVB-ADAT converter and possibly add one or two more expansion boards - fantastic.

Still, I would think that a network connection instead of an USB connection is a feasible alternative - if not even a better one. Because networked audio allows for more internetworked architectures instead of an USB setup that is bound to one host.

I wouldn't mind working on an AVB component - for that matter - but I'd need somebody to take care of the electronics side of things, being a software guy and all.

ps. the docs could do with some notes about the architecture and its modularity..

dspverden, 2020-05-06:
You can easily build an avb interface card with the XMOS stuff. From hardware side you can connect up to 64 channels to the infinitas mainboard. You need some clever routing inside the CPLD.
To me AVB is not so attractive. It requires special hardware. There are not so many network interfaces supporting AVB. Except Apple of course. There AVB is supported by the hardware out of the box. And you need special switches if you want to connect more then one AVB device.

tschiemer, 2020-05-11:
Hi! Thanks thanks for the input!

It's true that the problem about AVB is that is not so easygoing to integrate, ie little (affordable) hardware out there supports it.
Regarding networked audio, I would go for Dante if not for the general price tag which I also assume to be due to licensing costs. AES67 might be a plausible alternative here which - as I understand - would also integrate well with any Dante systems which can be found here and there.  But I'm not sure there is a low-cost solution which provides AES67 connectivity out of the box. I see the [BACH Minuet from ROSS](https://www.rossvideo.com/oem-developer/bach-minuet-st2110-aes67-audio-networking-soc-pdk/); I inquired about the price thereof but have not yet heard anything.

But well, it would be possible to write a software stack for XMOS chips to provide AES67 connectivity. I guess an interesting possibility. Has been done before, just commercially..
https://audioxpress.com/news/attero-tech-helps-solving-the-audio-over-ip-puzzle

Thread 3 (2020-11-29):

No DSP board/schematic

octave, 2020-11-29:
Hi,

Thanks for that awesome project! I'm about to build the infinitas board with bunch Analog IO boards but I would like to remove all dsp features and keep it as bare as possible. Is it something you already published (schematic)? Or should I do it myself from the Kicad files?

Thanks again!

Octave

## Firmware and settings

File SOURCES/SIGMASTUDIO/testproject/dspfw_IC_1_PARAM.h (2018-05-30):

/*
 * File:           E:\Documents\KiCAD\projekte\freeDSP\freeDSP-Infinitas\SOURCES\SIGMASTUDIO\testproject\dspfw_IC_1_PARAM.h
 *
 * Created:        Monday, January 29, 2018 3:33:37 PM
 * Description:    testproject:IC 1 parameter RAM definitions.
 *
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
 * This software may only be used to program products purchased from
 * Analog Devices for incorporation by you into audio products that
 * are intended for resale to audio product end users. This software
 * may not be distributed whole or in any part to third parties.
 *
 * Copyright ©2018 Analog Devices, Inc. All rights reserved.
 */
#ifndef __DSPFW_IC_1_PARAM_H__
#define __DSPFW_IC_1_PARAM_H__


/* Module SafeLoadModule - SafeLoadModule*/
#define MOD_SAFELOADMODULE_COUNT                       7
#define MOD_SAFELOADMODULE_DEVICE                      "IC1"
#define MOD_SAFELOADMODULE_DATA_SAFELOAD0_ADDR         20
#define MOD_SAFELOADMODULE_DATA_SAFELOAD1_ADDR         21
#define MOD_SAFELOADMODULE_DATA_SAFELOAD2_ADDR         22
#define MOD_SAFELOADMODULE_DATA_SAFELOAD3_ADDR         23
#define MOD_SAFELOADMODULE_DATA_SAFELOAD4_ADDR         24
#define MOD_SAFELOADMODULE_ADDRESS_SAFELOAD_ADDR       25
#define MOD_SAFELOADMODULE_NUM_SAFELOAD_ADDR           26

/* Module Tone1 - Sine Tone with Phase and Gain*/
#define MOD_TONE1_COUNT                                4
#define MOD_TONE1_DEVICE                               "IC1"
#define MOD_TONE1_ALG0_SINEPHASEGAINALGS3001GAIN00_ADDR 27
#define MOD_TONE1_ALG0_SINEPHASEGAINALGS3001GAIN00_VALUE SIGMASTUDIOTYPE_8_24_CONVERT(1)
#define MOD_TONE1_ALG0_SINEPHASEGAINALGS3001GAIN00_TYPE SIGMASTUDIOTYPE_8_24
#define MOD_TONE1_ALG0_SINEPHASEGAINALGS3001INDEXFPHI00_ADDR 28
#define MOD_TONE1_ALG0_SINEPHASEGAINALGS3001INDEXFPHI00_FIXPT 0x00000000
#define MOD_TONE1_ALG0_SINEPHASEGAINALGS3001INDEXFPHI00_VALUE SIGMASTUDIOTYPE_INTEGER_CONVERT(0)
#define MOD_TONE1_ALG0_SINEPHASEGAINALGS3001INDEXFPHI00_TYPE SIGMASTUDIOTYPE_INTEGER
#define MOD_TONE1_ALG0_SINEPHASEGAINALGS3001INDEXFPHI01_ADDR 29
#define MOD_TONE1_ALG0_SINEPHASEGAINALGS3001INDEXFPHI01_FIXPT 0x00000000
#define MOD_TONE1_ALG0_SINEPHASEGAINALGS3001INDEXFPHI01_VALUE SIGMASTUDIOTYPE_INTEGER_CONVERT(0)
#define MOD_TONE1_ALG0_SINEPHASEGAINALGS3001INDEXFPHI01_TYPE SIGMASTUDIOTYPE_INTEGER
#define MOD_TONE1_ALG0_INCREMENT_ADDR                  32
#define MOD_TONE1_ALG0_INCREMENT_VALUE                 SIGMASTUDIOTYPE_8_24_CONVERT(0.0416670833333333)
#define MOD_TONE1_ALG0_INCREMENT_TYPE                  SIGMASTUDIOTYPE_8_24

/* Module Tone1_2 - Sine Tone with Phase and Gain*/
#define MOD_TONE1_2_COUNT                              4
#define MOD_TONE1_2_DEVICE                             "IC1"
#define MOD_TONE1_2_ALG0_SINEPHASEGAINALGS3002GAIN00_ADDR 37
#define MOD_TONE1_2_ALG0_SINEPHASEGAINALGS3002GAIN00_VALUE SIGMASTUDIOTYPE_8_24_CONVERT(1)
#define MOD_TONE1_2_ALG0_SINEPHASEGAINALGS3002GAIN00_TYPE SIGMASTUDIOTYPE_8_24
#define MOD_TONE1_2_ALG0_SINEPHASEGAINALGS3002INDEXFPHI00_ADDR 38
#define MOD_TONE1_2_ALG0_SINEPHASEGAINALGS3002INDEXFPHI00_FIXPT 0x00000000
#define MOD_TONE1_2_ALG0_SINEPHASEGAINALGS3002INDEXFPHI00_VALUE SIGMASTUDIOTYPE_INTEGER_CONVERT(0)
#define MOD_TONE1_2_ALG0_SINEPHASEGAINALGS3002INDEXFPHI00_TYPE SIGMASTUDIOTYPE_INTEGER
#define MOD_TONE1_2_ALG0_SINEPHASEGAINALGS3002INDEXFPHI01_ADDR 39
#define MOD_TONE1_2_ALG0_SINEPHASEGAINALGS3002INDEXFPHI01_FIXPT 0x00000000
#define MOD_TONE1_2_ALG0_SINEPHASEGAINALGS3002INDEXFPHI01_VALUE SIGMASTUDIOTYPE_INTEGER_CONVERT(0)
#define MOD_TONE1_2_ALG0_SINEPHASEGAINALGS3002INDEXFPHI01_TYPE SIGMASTUDIOTYPE_INTEGER
#define MOD_TONE1_2_ALG0_INCREMENT_ADDR                42
#define MOD_TONE1_2_ALG0_INCREMENT_VALUE               SIGMASTUDIOTYPE_8_24_CONVERT(0.02083375)
#define MOD_TONE1_2_ALG0_INCREMENT_TYPE                SIGMASTUDIOTYPE_8_24

#endif

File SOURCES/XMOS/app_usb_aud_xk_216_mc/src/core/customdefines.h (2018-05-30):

/**
 * @file       customdefines.h
 * @brief      Defines relating to device configuration and customisation.
 *             For xCORE-200 Audio MC Board
 * @author     Ross Owen, XMOS Limited
 */
#ifndef _CUSTOMDEFINES_H_
#define _CUSTOMDEFINES_H_

#include "user_main.h"

/*
 * Device configuration option defines to override default defines found devicedefines.h
 *
 * Build can be customised but changing and adding defines here
 *
 * Note, we check if they are already defined in Makefile
 */

#define PRODUCT_STR_A2           "infinitas DSP"

/* Default to board version version 2.0 */
#ifndef XCORE_200_MC_AUDIO_HW_VERSION
#define XCORE_200_MC_AUDIO_HW_VERSION 2
#endif

/* Tile defines */
#define AUDIO_IO_TILE      0
#define XUD_TILE           1

/* SPDIF Tx i/o moved tile between board versions 1.0 -> 2.0 */
#if XCORE_200_MC_AUDIO_HW_VERSION < 2
#define SPDIF_TX_TILE      1
#endif

#define MIDI_TILE          1

/* Mixer core enabled by default */
#ifndef MIXER
#define MIXER              1
#endif

/* Mixing disabled by default */
#ifndef MAX_MIX_COUNT
#define MAX_MIX_COUNT      0
#endif

/* Board is self-powered i.e. not USB bus-powered */
#define SELF_POWERED       1

/* Enable/Disable MIDI - Default is MIDI off */
#ifndef MIDI
#define MIDI 		       0
#endif

/* Enable/Disable SPDIF output - Default is S/PDIF on */
#ifndef SPDIF_TX
#define SPDIF_TX	       1
#endif

/* Defines relating to channel count and channel arrangement (Set to 0 for disable) */
//:audio_defs
/* Number of USB streaming channels - Default is 4 in 4 out */
#ifndef NUM_USB_CHAN_IN
#define NUM_USB_CHAN_IN    (10)         /* Device to Host */
#endif
#ifndef NUM_USB_CHAN_OUT
#define NUM_USB_CHAN_OUT   (10)         /* Host to Device */
#endif

/* Number of IS2 chans to DAC..*/
#ifndef I2S_CHANS_DAC
#define I2S_CHANS_DAC      (8)
#endif

/* Number of I2S chans from ADC */
#ifndef I2S_CHANS_ADC
#define I2S_CHANS_ADC      (8)
#endif

/* Channel index of SPDIF Rx channels (duplicated DAC channels 1/2 when index is 0) */
#define SPDIF_TX_INDEX     (8)

/* Channel index of SPDIF Rx channels */
#define SPDIF_RX_INDEX     (8)

/* Channel index of ADAT Tx channels */
#if defined(SPDIF_TX) && (SPDIF_TX==1)
#define ADAT_TX_INDEX      (SPDIF_TX_INDEX + 2)
#else
#define ADAT_TX_INDEX      (I2S_CHANS_DAC)
#endif

/* Channel index of ADAT Rx channels */
#if defined(SPDIF_RX) && (SPDIF_RX==1)
#define ADAT_RX_INDEX      (SPDIF_RX_INDEX + 2)
#else
#define ADAT_RX_INDEX      (I2S_CHANS_ADC)
#endif

/* Master clock defines (in Hz) */
#define MCLK_441           (512*44100)   /* 44.1, 88.2 etc */
#define MCLK_48            (512*48000)   /* 48, 96 etc */

/* Maximum frequency device runs at */
#ifndef MAX_FREQ
#define MAX_FREQ           (192000)
#endif

#ifndef MIN_FREQ
#define MIN_FREQ                 (48000)
#endif

#define UAC_FORCE_FEEDBACK_EP (1)
//:
/***** Defines relating to USB descriptors etc *****/
//:usb_defs
#define VENDOR_ID          (0x20B1) /* XMOS VID */
#define PID_AUDIO_2        (0x0008) /* SKC_SU1 USB Audio Reference Design PID */
#define PID_AUDIO_1        (0x0009) /* SKC_SU1 Audio Reference Design PID */
//:

/* Enable/Disable example HID code */
#ifndef HID_CONTROLS
#define HID_CONTROLS       1
#endif

//#define CODEC_MASTER       (1)

#endif

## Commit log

2018-05-30 First PCB layout in 'freeDSP style'
    [1-freeDSP-Infinitas-TopSilkscreen.gbr, 2-freeDSP-Infinitas-TopSoldermask.gbr, 3-freeDSP-Infinitas-TopLayer.gbr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]
2018-05-30 New PCB layout
    [adc01.sch, adc02.sch, dac01.sch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]
2018-05-30 Prototype with 2x freeDSPx-BAL-IO-x8 on same panel
    [1-freeDSP-Infinitas-TopSilkscreen.gbr, 2-freeDSP-Infinitas-TopSoldermask.gbr, 3-freeDSP-Infinitas-TopLayer.gbr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]
2018-05-30 Added BOM
2018-06-22 Add i2c configuration of AK4458
    Notice the hack of the i2c modules (LICENSE OF XMOS STUFF IS UNCLEAR)
    [infinitas.sch]
2018-08-01 Bugfix on i2c multiplexer
    [adc01.sch, adc02.sch, dac01.sch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]
2018-08-01 Reset forwarded to FPGA
    [infinitas.kicad_pcb, infinitas.sch]
2018-09-04 Changed USBi connector
    [dsp.sch, dsp_old.sch, infinitas einzeln.csv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]
2018-09-04 Updated BOM
    [BOM release 1.0.0.csv, infinitas.csv]
2018-09-05 Upgraded to KiCAD 5
    [dsp-2018-09-05-14-38-09.sch, dsp.sch, infinitas-2018-09-05-14-38-09.sch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]
2018-09-19 Exported Gerbers
    [infinitas.kicad_pcb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]
2018-10-12 Bugfix on Silkscreen
    [dsp.sch, infinitas.kicad_pcb, infinitas.sch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]
2018-10-14 Updated VHDL code
    [dsp.sch, uac2-if.sch]
2018-10-16 New Gerber export
    [infinitas.kicad_pcb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]
